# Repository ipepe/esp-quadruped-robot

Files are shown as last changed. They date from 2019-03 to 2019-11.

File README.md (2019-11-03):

# ESP Quadruped Robot
This is open soruce quadruped robot with 3D Printable files and firmware for ESP8266 (In my case Wemos D1 Mini).

It is based on Jason's Workshop Q1 Mini and Q1 Lite projects:
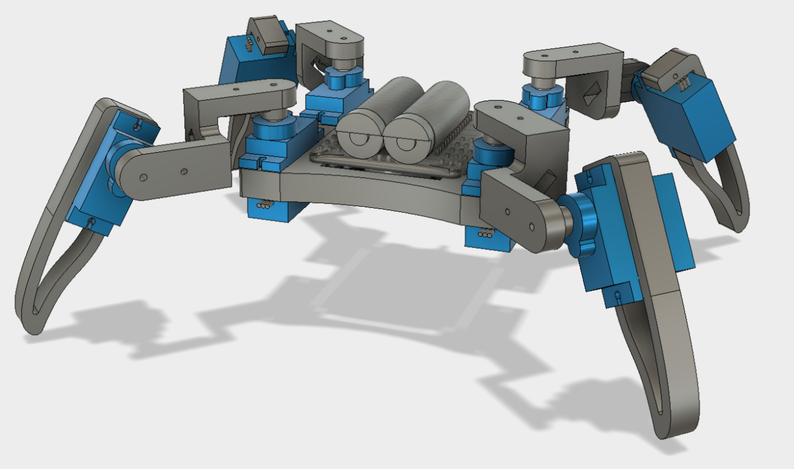
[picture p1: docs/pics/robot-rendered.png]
ESP Quadruped Robot rendered


For firmware components I used:
 * https://github.com/me-no-dev/ESPAsyncWebServer
 * https://github.com/tzapu/WiFiManager
 * https://github.com/esp8266/Arduino/blob/master/libraries/ArduinoOTA/examples/BasicOTA/BasicOTA.ino

## Control Interface
Its based on Bootstrap table with gamepad controls. Should work in offline mode.
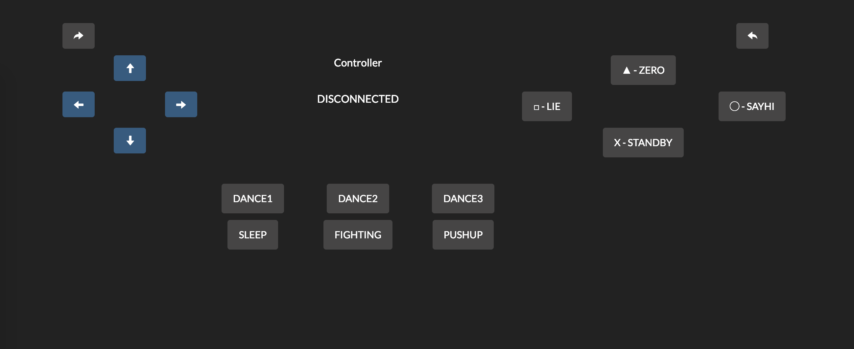
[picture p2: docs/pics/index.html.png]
Control Interface Screenshot


## Instructions
Original Jason's instruction:
https://drive.google.com/drive/folders/1iiuYHSkZpUuZ23yAdjj1NX9eLKb6hHGm

## Programming

It is worth noting that You need to upload data folder into SPIFFS. Otherwise You might get internal server Error 500 while trying to access microcontroller's web server.

## Bill of Materials

### Electronics
* 1x Wemos D1 Mini or alternative
* 8x Servo MG90S or alternative

### 3D Printed
* 1x stl_files/body.stl
* 4x stl_files/foot.stl
* 2x stl_files/thigh.stl (with supports)
* 2x stl_files/thigh_mirror.stl (with supports)

# Changes made from Jason Workshop resources
Simple but brief: I redesigned body and leg stl files. I rewrote firmware for ESP8266 leaving only code responsible for animatronics (moving servos).

Complex but detailed:
[Diff between original-jason-workshop branch and master](https://github.com/ipepe/esp-quadruped-robot/compare/original-jason-workshop...master)

# License

This project licensed under the

Attribution-NonCommercial-ShareAlike 4.0 International (CC BY-NC-SA 4.0)

License Deed

https://creativecommons.org/licenses/by-nc-sa/4.0/

You are free to:

Share - copy and redistribute the material in any medium or format

Adapt- remix, transform, and build upon the material

The licensor cannot revoke these freedoms as long as you follow the license terms.

Under the following terms:

Attribution - You must give appropriate credit, provide a link to the license, and indicate if changes were made. You may do so in any reasonable manner, but not in any way that suggests the licensor endorses you or your use.

NonCommercial - You may not use the material for commercial purposes.

ShareAlike - If you remix, transform, or build upon the material, you must distribute your contributions under the same license as the original.

No additional restrictions - You may not apply legal terms or technological measures that legally restrict others from doing anything the license permits.

Credit:

Q1 mini - Quadruped Robot (Designed by Jason Workshop)

Q1 lite - Quadruped Robot (Designed by Jason Workshop)

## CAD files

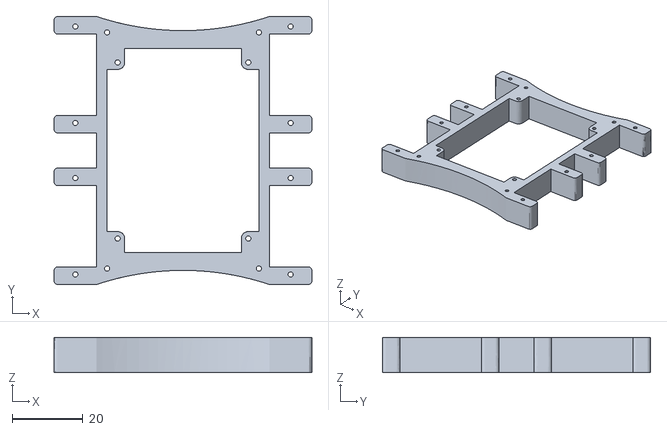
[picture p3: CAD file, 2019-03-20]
stl_files/body.stl
73.0 x 75.9 x 10.0

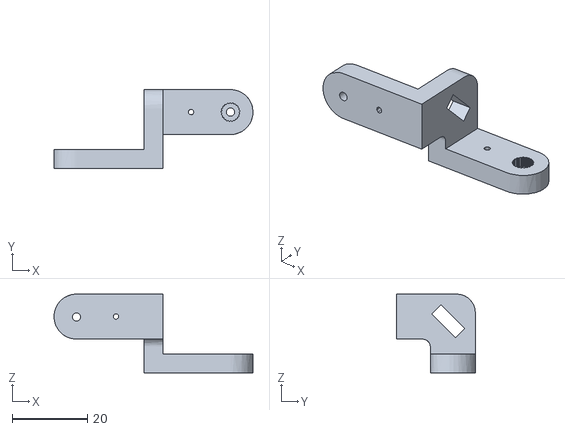
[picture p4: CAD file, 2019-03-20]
stl_files/thigh_mirror.stl
53.0 x 21.0 x 21.0

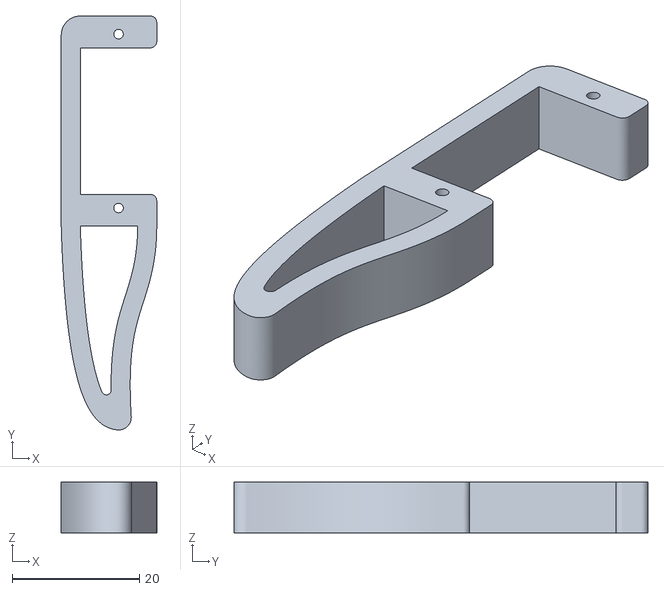
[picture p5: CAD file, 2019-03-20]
stl_files/foot.stl
15.0 x 65.0 x 8.00

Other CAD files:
stl_files/thigh.stl

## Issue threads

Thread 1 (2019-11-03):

ERROR 500

nikil511, 2019-11-03:
I'm building the source in platformio, using the latest versions of everything.
It connectes to my wifi network, but upon access I get an error 500.

Can you please specify which SDK & Lib versions give you a working system?
(thanks!)

ipepe, 2019-11-03:
Did You upload data folder to SPIFFS?

nikil511, 2019-11-03:
Oups! :-)
ok, confirm that after running “**Upload File System image**” in platformio it works!
(thanks again!)

ipepe, 2019-11-03:
No problem. I have to warn You that this project was still very **work in progress** in the means of STL files and also the code. This instruction by Jason is also worth reading/skimming through as there are few quirks in assembly in positioning servos: https://drive.google.com/drive/folders/1iiuYHSkZpUuZ23yAdjj1NX9eLKb6hHGm

ipepe, 2019-11-03:
I'm closing this issue. I added info about instruction and uploading to SPIFFS into Readme.md

ipepe, 2019-11-03:
@nikil511 I will add last two cents:
1. While doing this on ESP8266 is possible (like Wemos D1 Mini) is had problems when I was flashing while connected to servos, because some servo pins are brought to UP state or DOWN while flashing and it may damage the servo (because it might try to go over it's maximum angles and damage sprockets.

2. What I think would be a better idea, is to upgrade to ESP32 and change all firmware basis into Espruino. Main motivator for that is this video: https://youtu.be/drW47F3GywU?t=1144

It gives ability to connect via bluetooth and easier manipulation of the code. ESP32 has more pins which could be used for servos freely without colliding with pins that are used for flashing. Espruino code can be uploaded without flashing firmware so it's possible to upload code easier and prototype on the fly with REPL. You could even setup a link where there could be a newest version of firmware to download through internet.

nikil511, 2019-11-03:
thanks for the tips, I am using this skeleton: https://www.thingiverse.com/thing:3874202 as a starting point, and aspire to modify it in the future.
As for ESP32, in fact, I just did the port from your code.
(link will follow)

ipepe, 2019-11-03:
@nikil511 Let me know how it goes, also if You need help or someone to bounce ideas off then hit me up at patryk@ipepe.pl

Closed 2019-11-03.

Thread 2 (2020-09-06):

Problems booting the board

Limon93, 2020-09-06:
Hello ipepe,
i managed to compile and upload spiffs on board but i was not able to get any result from it, nothing happens, the serial stays quiet too, do you have any suggestions? I also tried two different boards.
Using arduino 1.8.5 and esp8266sdk 2.7.0

Limon93, 2020-09-11:
Solved, had to select basic SSL ciphers support in board settings.

Closed 2020-09-11.

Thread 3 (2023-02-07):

Servo turning too slow

ArjuAdhmika, 2023-02-07:
i use wemos d1 mini and connect my servo signal pin to it, and i'm using xl6009 buck boost converter for servo 5v and lm2596 buck converter for wemos 5v and all the ground connected, but my servo is turning slow and not in full range of motion

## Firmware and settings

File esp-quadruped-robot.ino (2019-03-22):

#include <ESP8266WiFi.h>
#include "ESPAsyncWebServer.h"
#include <ArduinoOTA.h>
#include <Servo.h>
#include <EEPROM.h>
#include <SPIFFSEditor.h>
#include <ESPAsyncWiFiManager.h>         //https://github.com/tzapu/WiFiManager
#include "animations.h"

AsyncWebServer server(80);
DNSServer dns;

const uint8_t FRONT_RIGHT_FOOT = D7;
const uint8_t FRONT_RIGHT_LEG = D6;

const uint8_t REAR_RIGHT_LEG = D5;
const uint8_t REAR_RIGHT_FOOT = D8;

const uint8_t FRONT_LEFT_FOOT = D3;
const uint8_t FRONT_LEFT_LEG = D2;

const uint8_t REAR_LEFT_LEG = D1;
const uint8_t REAR_LEFT_FOOT = D4;

const int numberOfServos = 8; // Number of servos

//calibration legs FRF, FRL, RRL, RRF, FLF, FLL, RLL, RLF
int servoCal[] = {   0,   0,   0,   0,   0,   0,   0,   0 }; // Servo calibration data
int servoPos[] = {   135,  45, 135,  45,  45, 135,  45, 135 }; // Servo current position
const int servoPrgPeriod = 20; // 20 ms
int nextAnimation = -1;
int newAction = -1;
Servo servo[numberOfServos];

// EEPROM Clear (For debug only)
void eepromClear()
{
  for (int i = 0; i < EEPROM.length(); i++) {
    EEPROM.write(i, 0);
  }
}

// Get servoCal from EEPROM
void getServoCal()
{
  int eeAddress = 0;
  for (int i = 0; i < numberOfServos; i++) {
    EEPROM.get(eeAddress, servoCal[i]);
    eeAddress += sizeof(servoCal[i]);
  }
}

// Put servoCal to EEPROM
void putServoCal()
{
  int eeAddress = 0;
  for (int i = 0; i < numberOfServos; i++) {
    EEPROM.put(eeAddress, servoCal[i]);
    eeAddress += sizeof(servoCal[i]);
  }
}

// Clear Servo calibration data
void clearCal()
{
  for (int i = 0; i < numberOfServos; i++) {
    servoCal[i] = 0;
  }
  putServoCal(); // Put servoCal to EEPROM
  runServoPrg(servoPrg00, servoPrg00step); // zero position
}

// Calibration
void calibration(int i, int change)
{
  servoCal[i] = servoCal[i] + change;
  servo[i].write(servoAct00[i] + servoCal[i]);
  putServoCal(); // Put servoCal to EEPROM
  delay(400);
}

void runServoPrg(int servoPrg[][numberOfACE], int step)
{
  for (int i = 0; i < step; i++) { // Loop for step

    int totalTime = servoPrg[i][numberOfACE - 1]; // Total time of this step

    // Get servo start position
    for (int s = 0; s < numberOfServos; s++) {
      servoPos[s] = servo[s].read() - servoCal[s];
    }

    for (int j = 0; j < totalTime / servoPrgPeriod; j++) { // Loop for time section
      for (int k = 0; k < numberOfServos; k++) { // Loop for servo
        servo[k].write((map(j, 0, totalTime / servoPrgPeriod, servoPos[k], 180 - servoPrg[i][k])) + servoCal[k]);
      }
      delay(servoPrgPeriod);
    }
  }
}

void setup() {
  servo[0].attach(FRONT_RIGHT_FOOT);
  servo[1].attach(FRONT_RIGHT_LEG);
  servo[2].attach(REAR_RIGHT_LEG);
  servo[3].attach(REAR_RIGHT_FOOT);
  servo[4].attach(FRONT_LEFT_FOOT);
  servo[5].attach(FRONT_LEFT_LEG);
  servo[6].attach(REAR_LEFT_LEG);
  servo[7].attach(REAR_LEFT_FOOT);
  runServoPrg(servoPrg01, servoPrg01step); // zero position

  Serial.begin(115200);
  Serial.println("Booted");
  // Initialize SPIFFS
  if(!SPIFFS.begin()){
    Serial.println("An Error has occurred while mounting SPIFFS");
    return;
  }

  AsyncWiFiManager wifiManager(&server,&dns);
  wifiManager.autoConnect();
  ArduinoOTA.setHostname("quadruped-v1-wemos-d1-mini");
  ArduinoOTA.begin();

  server.on("/api/move", [](AsyncWebServerRequest *request){
    if(request->hasParam("action")){
        newAction = request->arg("action").toInt();
        if(newAction >= 0 && newAction <= 15){
            nextAnimation = newAction;
            request->send(200, "text/plain", "ok");
        }else{
            request->send(404, "text/plain", "error");
        }
    }else{
        request->send(404, "text/plain", "error");
    }
  });
  server.serveStatic("/", SPIFFS, "/").setDefaultFile("index.html");
  server.begin();

  delay(300);
  runServoPrg(servoPrg01, servoPrg01step); // zero position

  Serial.println("End of setup");
}

void loop() {
  ArduinoOTA.handle();
  if(nextAnimation != -1){
    switch(nextAnimation){
    case 0:
        runServoPrg(servoPrg00, servoPrg00step);
        break;
    case 1:
        runServoPrg(servoPrg01, servoPrg01step);
        break;
    case 2:
        runServoPrg(servoPrg02, servoPrg02step);
        break;
    case 3:
        runServoPrg(servoPrg03, servoPrg03step);
        break;
    case 4:
        runServoPrg(servoPrg04, servoPrg04step);
        break;
    case 5:
        runServoPrg(servoPrg05, servoPrg05step);
        break;
    case 6:
        runServoPrg(servoPrg06, servoPrg06step);
        break;
    case 7:
        runServoPrg(servoPrg07, servoPrg07step);
        break;
    case 8:
        runServoPrg(servoPrg08, servoPrg08step);
        break;
    case 9:
        runServoPrg(servoPrg09, servoPrg09step);
        break;
    case 10:
        runServoPrg(servoPrg10, servoPrg10step);
        break;
    case 11:
        runServoPrg(servoPrg11, servoPrg11step);
        break;
    case 12:
        runServoPrg(servoPrg12, servoPrg12step);
        break;
    case 13:
        runServoPrg(servoPrg13, servoPrg13step);
        break;
    case 14:
        runServoPrg(servoPrg14, servoPrg14step);
        break;
    case 15:
        runServoPrg(servoPrg15, servoPrg15step);
        break;
    default:
        break;
    }
    nextAnimation = -1;
  }
}

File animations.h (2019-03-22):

const int numberOfACE = 9; // Number of action code elements

// Servo calibration position
// -------------------------- P02, P03, P05, P15, P07, P08, P11, P16
int servoAct00 [] PROGMEM = { 135,  45, 135,  45,  45, 135,  45, 135 };

// Zero
int servoPrg00step = 1;
int servoPrg00 [][numberOfACE] PROGMEM = {
  // P02, P03, P05, P15, P07, P08, P11, P16,  ms
  {  135,  45, 135,  45,  45, 135,  45, 135,  400  }, // zero position
};

// Standby
int servoPrg01step = 2;
int servoPrg01 [][numberOfACE] PROGMEM = {
  // P02, P03, P05, P15, P07, P08, P11, P16,  ms
  {   90,  90,  90,  90,  90,  90,  90,  90,  200  }, // servo center point
  {   70,  90,  90, 110, 110,  90,  90,  70,  200  }, // standby
};

// Forward
int servoPrg02step = 11;
int servoPrg02 [][numberOfACE] PROGMEM = {
  // P02, P03, P05, P15, P07, P08, P11, P16,  ms
  {   70,  90,  90, 110, 110,  90,  90,  70,  100  }, // standby
  {   90,  90,  90, 110, 110,  90,  45,  90,  100  }, // leg1,4 up; leg4 fw
  {   70,  90,  90, 110, 110,  90,  45,  70,  100  }, // leg1,4 dn
  {   70,  90,  90,  90,  90,  90,  45,  70,  100  }, // leg2,3 up
  {   70,  45, 135,  90,  90,  90,  90,  70,  100  }, // leg1,4 bk; leg2 fw
  {   70,  45, 135, 110, 110,  90,  90,  70,  100  }, // leg2,3 dn
  {   90,  90, 135, 110, 110,  90,  90,  90,  100  }, // leg1,4 up; leg1 fw
  {   90,  90,  90, 110, 110, 135,  90,  90,  100  }, // leg2,3 bk
  {   70,  90,  90, 110, 110, 135,  90,  70,  100  }, // leg1,4 dn
  {   70,  90,  90, 110,  90, 135,  90,  70,  100  }, // leg3 up
  {   70,  90,  90, 110, 110,  90,  90,  70,  100  }, // leg3 fw dn
};

// Backward
int servoPrg03step = 11;
int servoPrg03 [][numberOfACE] PROGMEM = {
  // P02, P03, P05, P15, P07, P08, P11, P16,  ms
  {   70,  90,  90, 110, 110,  90,  90,  70,  100  }, // standby
  {   90,  45,  90, 110, 110,  90,  90,  90,  100  }, // leg4,1 up; leg1 fw
  {   70,  45,  90, 110, 110,  90,  90,  70,  100  }, // leg4,1 dn
  {   70,  45,  90,  90,  90,  90,  90,  70,  100  }, // leg3,2 up
  {   70,  90,  90,  90,  90, 135,  45,  70,  100  }, // leg4,1 bk; leg3 fw
  {   70,  90,  90, 110, 110, 135,  45,  70,  100  }, // leg3,2 dn
  {   90,  90,  90, 110, 110, 135,  90,  90,  100  }, // leg4,1 up; leg4 fw
  {   90,  90, 135, 110, 110,  90,  90,  90,  100  }, // leg3,1 bk
  {   70,  90, 135, 110, 110,  90,  90,  70,  100  }, // leg4,1 dn
  {   70,  90, 135,  90, 110,  90,  90,  70,  100  }, // leg2 up
  {   70,  90,  90, 110, 110,  90,  90,  70,  100  }, // leg2 fw dn
};

// Move Left
int servoPrg04step = 11;
int servoPrg04 [][numberOfACE] PROGMEM = {
  // P02, P03, P05, P15, P07, P08, P11, P16,  ms
  {   70,  90,  90, 110, 110,  90,  90,  70,  100  }, // standby
  {   70,  90,  45,  90,  90,  90,  90,  70,  100  }, // leg3,2 up; leg2 fw
  {   70,  90,  45, 110, 110,  90,  90,  70,  100  }, // leg3,2 dn
  {   90,  90,  45, 110, 110,  90,  90,  90,  100  }, // leg1,4 up
  {   90, 135,  90, 110, 110,  45,  90,  90,  100  }, // leg3,2 bk; leg1 fw
  {   70, 135,  90, 110, 110,  45,  90,  70,  100  }, // leg1,4 dn
  {   70, 135,  90,  90,  90,  90,  90,  70,  100  }, // leg3,2 up; leg3 fw
  {   70,  90,  90,  90,  90,  90, 135,  70,  100  }, // leg1,4 bk
  {   70,  90,  90, 110, 110,  90, 135,  70,  100  }, // leg3,2 dn
  {   70,  90,  90, 110, 110,  90, 135,  90,  100  }, // leg4 up
  {   70,  90,  90, 110, 110,  90,  90,  70,  100  }, // leg4 fw dn
};

// Move Right
int servoPrg05step = 11;
int servoPrg05 [][numberOfACE] PROGMEM = {
  // P02, P03, P05, P15, P07, P08, P11, P16,  ms
  {   70,  90,  90, 110, 110,  90,  90,  70,  100  }, // standby
  {   70,  90,  90,  90,  90,  45,  90,  70,  100  }, // leg2,3 up; leg3 fw
  {   70,  90,  90, 110, 110,  45,  90,  70,  100  }, // leg2,3 dn
  {   90,  90,  90, 110, 110,  45,  90,  90,  100  }, // leg4,1 up
  {   90,  90,  45, 110, 110,  90, 135,  90,  100  }, // leg2,3 bk; leg4 fw
  {   70,  90,  45, 110, 110,  90, 135,  70,  100  }, // leg4,1 dn
  {   70,  90,  90,  90,  90,  90, 135,  70,  100  }, // leg2,3 up; leg2 fw
  {   70, 135,  90,  90,  90,  90,  90,  70,  100  }, // leg4,1 bk
  {   70, 135,  90, 110, 110,  90,  90,  70,  100  }, // leg2,3 dn
  {   90, 135,  90, 110, 110,  90,  90,  70,  100  }, // leg1 up
  {   70,  90,  90, 110, 110,  90,  90,  70,  100  }, // leg1 fw dn
};

// Turn left
int servoPrg06step = 8;
int servoPrg06 [][numberOfACE] PROGMEM = {
  // P02, P03, P05, P15, P07, P08, P11, P16,  ms
  {   70,  90,  90, 110, 110,  90,  90,  70,  100  }, // standby
  {   90,  90,  90, 110, 110,  90,  90,  90,  100  }, // leg1,4 up
  {   90, 135,  90, 110, 110,  90, 135,  90,  100  }, // leg1,4 turn
  {   70, 135,  90, 110, 110,  90, 135,  70,  100  }, // leg1,4 dn
  {   70, 135,  90,  90,  90,  90, 135,  70,  100  }, // leg2,3 up
  {   70, 135, 135,  90,  90, 135, 135,  70,  100  }, // leg2,3 turn
  {   70, 135, 135, 110, 110, 135, 135,  70,  100  }, // leg2,3 dn
  {   70,  90,  90, 110, 110,  90,  90,  70,  100  }, // leg1,2,3,4 turn
};

// Turn right
int servoPrg07step = 8;
int servoPrg07 [][numberOfACE] PROGMEM = {
  // P02, P03, P05, P15, P07, P08, P11, P16,  ms
  {   70,  90,  90, 110, 110,  90,  90,  70,  100  }, // standby
  {   70,  90,  90,  90,  90,  90,  90,  70,  100  }, // leg2,3 up
  {   70,  90,  45,  90,  90,  45,  90,  70,  100  }, // leg2,3 turn
  {   70,  90,  45, 110, 110,  45,  90,  70,  100  }, // leg2,3 dn
  {   90,  90,  45, 110, 110,  45,  90,  90,  100  }, // leg1,4 up
  {   90,  45,  45, 110, 110,  45,  45,  90,  100  }, // leg1,4 turn
  {   70,  45,  45, 110, 110,  45,  45,  70,  100  }, // leg1,4 dn
  {   70,  90,  90, 110, 110,  90,  90,  70,  100  }, // leg1,2,3,4 turn
};

// Lie
int servoPrg08step = 1;
int servoPrg08 [][numberOfACE] PROGMEM = {
  // P02, P03, P05, P15, P07, P08, P11, P16,  ms
  {  110,  90,  90,  70,  70,  90,  90, 110,  500  }, // leg1,4 up
};

// Say Hi
int servoPrg09step = 4;
int servoPrg09 [][numberOfACE] PROGMEM = {
  // P02, P03, P05, P15, P07, P08, P11, P16,  ms
  {  120,  90,  90, 110,  60,  90,  90,  70,  200  }, // leg1, 3 down
  {   70,  90,  90, 110, 110,  90,  90,  70,  200  }, // standby
  {  120,  90,  90, 110,  60,  90,  90,  70,  200  }, // leg1, 3 down
  {   70,  90,  90, 110, 110,  90,  90,  70,  200  }, // standby
};
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

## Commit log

2019-03-20 Added original Jason Workshop resources
    [body.stl, bodyBottom.stl, bodyCover.stl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]
2019-03-20 My Initial Version
    [body.stl, bodyBottom.stl, bodyCover.stl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]
2019-03-20 Fixed typo in servo name
